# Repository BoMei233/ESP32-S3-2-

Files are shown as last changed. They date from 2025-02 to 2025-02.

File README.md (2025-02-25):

# ESP32-S3 欧卡2组合开关
使用PlatformIO，包含了源代码和模型文件，可以自己DIY组合开关

## 1. 购买清单
**后面我会给出我的购买截图，请注意型号**
| 名称 | 数量  |
| :---: | :---: |
| ESP32-S3开发板 | 1 |
| 104电容 |  16 |
| 加厚角码直角60x120x40 | 2 |
| 五菱荣光雨刷拨杆 A款 | 1 |
| 五菱荣光灯光拨杆 A款 | 1 |
| 4.8插簧线/条 |  13 |
| M3*5杯头螺丝 | 8 |
| M3x4x4.2热熔螺母 | 8 |
| M5法兰螺母 | 4 |
| M5*16杯头螺丝 | 4 |
| M5*12*1平垫圈 | 4 |
| 10P航插(插头+插座一套) | 1 |
| 8P航插(插头+插座一套) | 1 |
| 5x0.15平方硅胶线 | 1 |
| 8x0.15平方硅胶线 | 1 |
| 醋酸胶布(非必须，用于固定线束) | 1 |

### 注意事项：
1.角码需要在远端打个5mm的孔以适配V99基座，千万不要买大一号的\
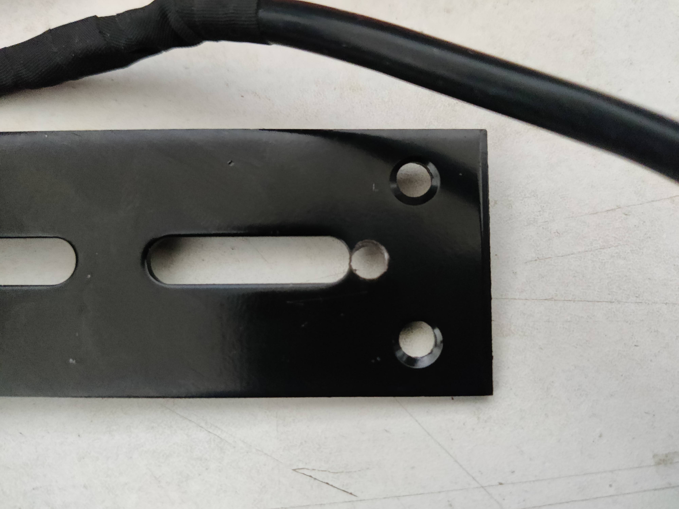
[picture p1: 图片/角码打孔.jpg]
角码打孔孔位


## 2. 组装步骤

### 2.1 转向灯开关
#### 2.1.1 转向灯开关插簧连接
    按照下图所示，将插簧线插入转向灯开关，插簧插入方向任意
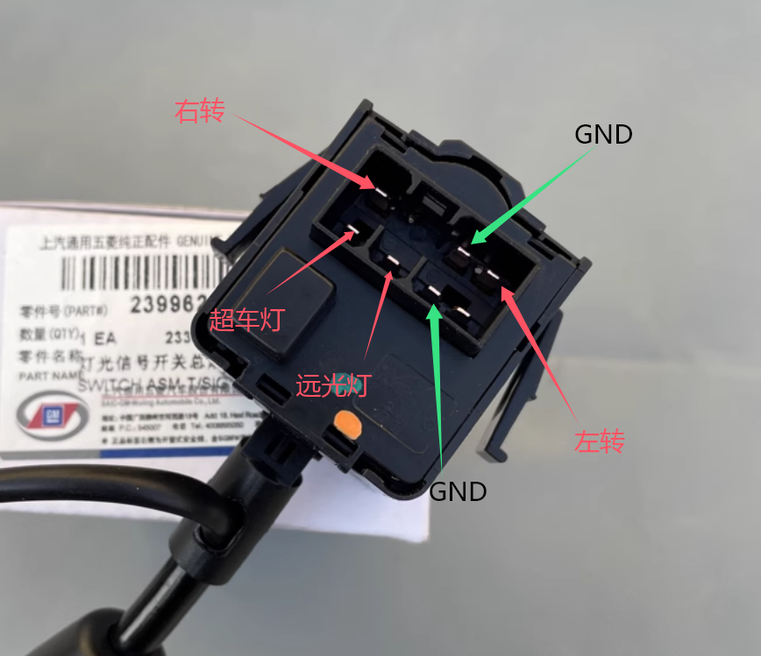
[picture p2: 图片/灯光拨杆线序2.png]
灯光拨杆线序2

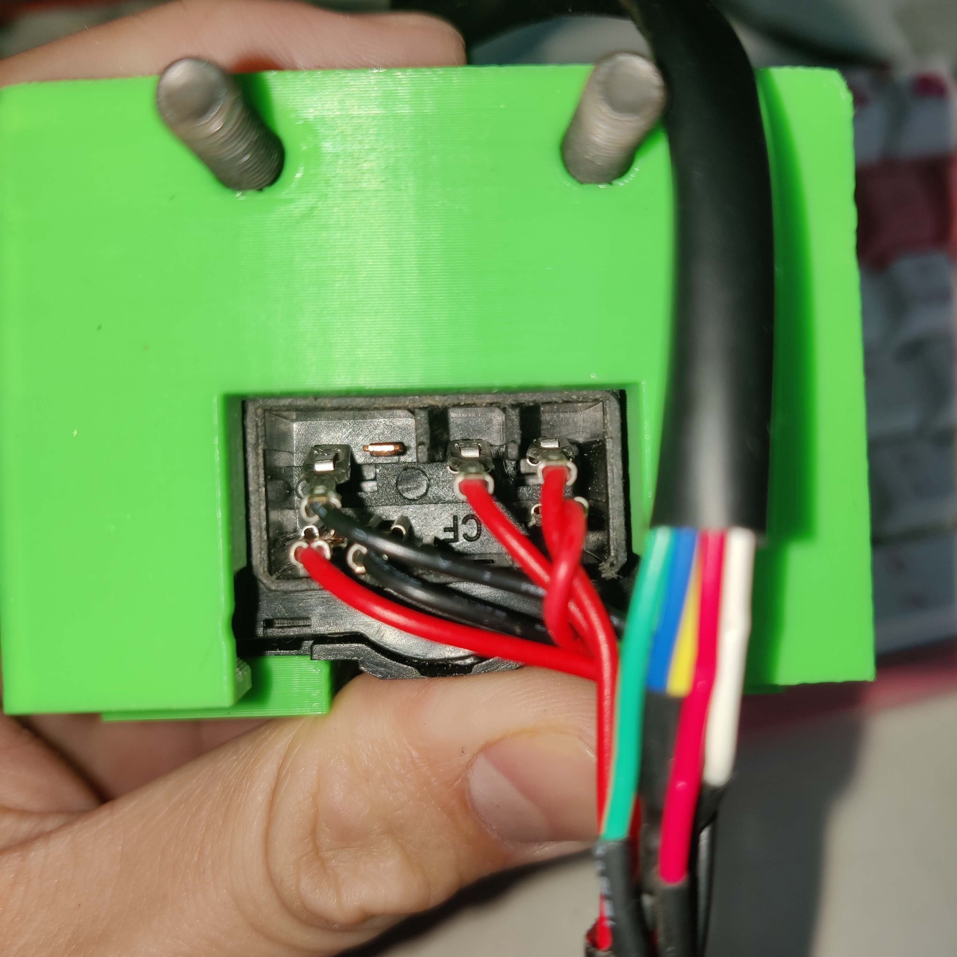
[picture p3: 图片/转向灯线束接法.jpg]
转向灯线束接法


#### 2.1.2 转向灯开关手柄线束连接
    下图给出了手柄五根线具体的作用，将两根GND与插簧线的GND并联在一起：
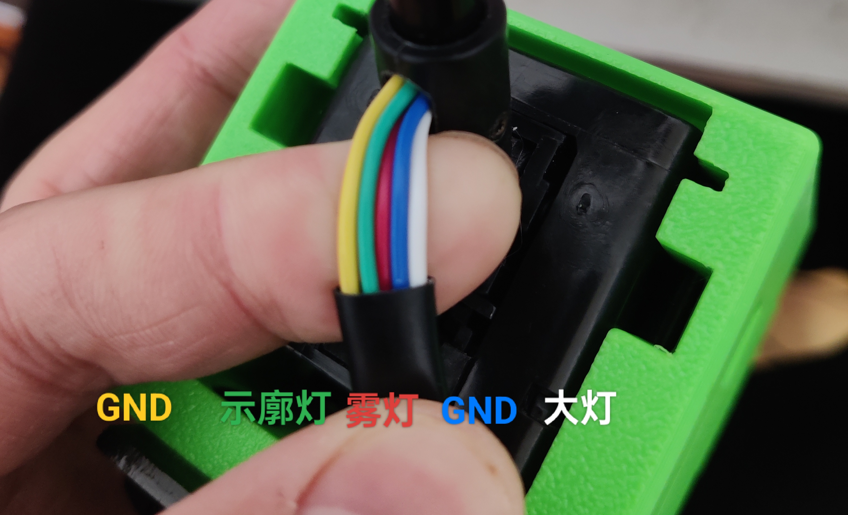
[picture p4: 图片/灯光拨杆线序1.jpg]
灯光拨杆线序1
\

至此，转向灯组合开关已经引出了8根线，将这8根线用“8x0.15平方硅胶线”延长，最后接到航空插头上。(请记住线序，航插上面会印有数字编号，这里买10P的用处是方便焊接，因为中间两根插针非常难焊接，因此使用四周的8根)

### 2.2 雨刮器开关
雨刮器相对简单，因为手柄没有线束，只需要插簧线。\
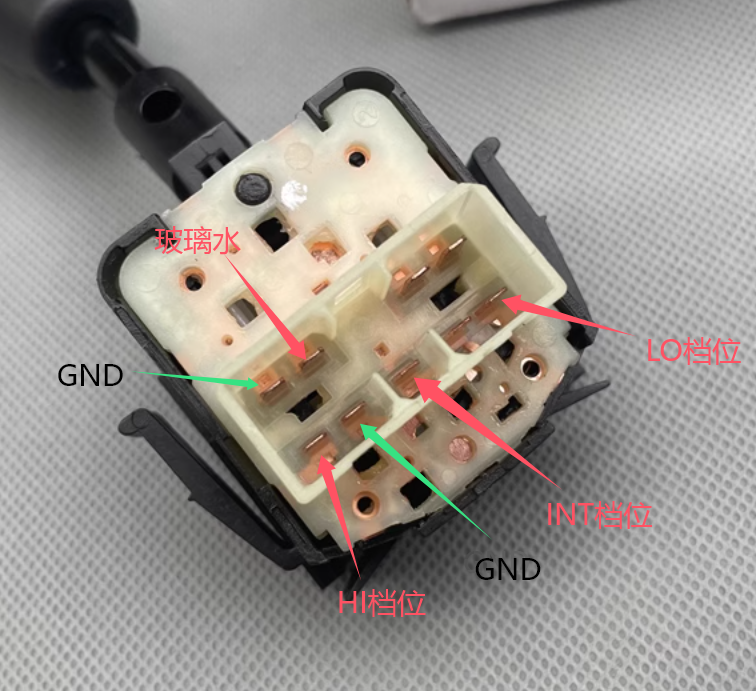
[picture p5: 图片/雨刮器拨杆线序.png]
雨刮器拨杆线序
\
现在将引出的5根线用“5x0.15平方硅胶线”延长，最后接到航空插头上。(请记住线序，航插上面会印有数字编号)

### 2.3 控制板组装
#### 2.3.1 控制板与洞洞板连接
这一步相对简单，只需要将航空插座上的引脚与开发板上的引脚对应连接起来就好，<span style="color: red;">记得在每个引脚与地之间并联一个104电容，这步非常重要！！！</span>如下图所示：
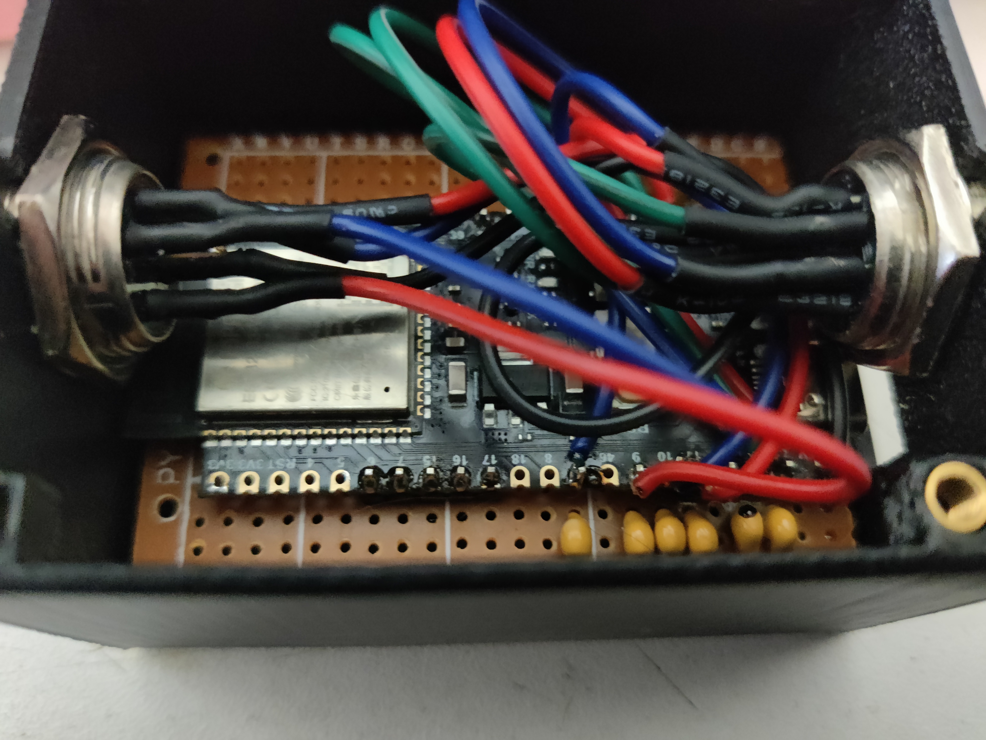
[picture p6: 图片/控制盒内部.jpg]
控制盒内部
\
使用洞洞板固定，将开发板焊接至洞洞板上即可，注意，需要将洞洞板短边剪去一排孔位，将USB接口与洞洞板边缘对齐，否则在装壳后USB线将无法插入。\
洞洞板尺寸为50x65mm，不一致的可以使用剪刀和砂纸进行修正。\
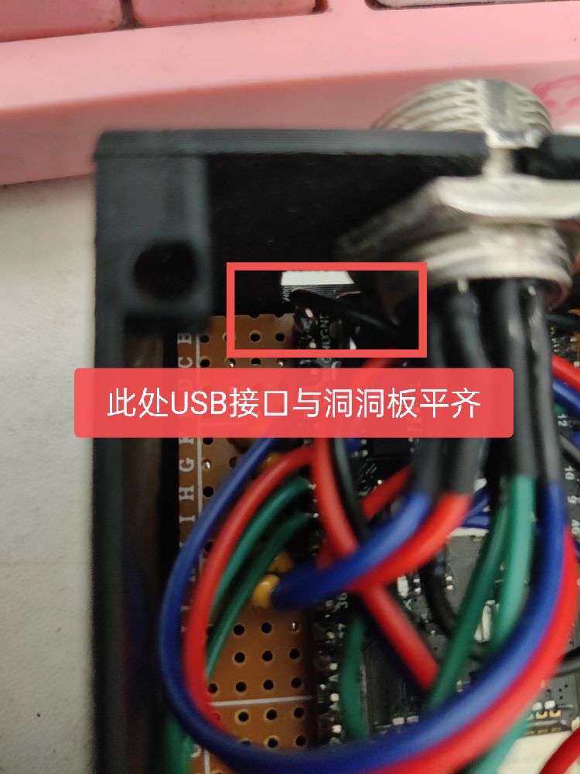
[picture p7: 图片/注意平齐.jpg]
注意平齐
\

#### 2.3.2 控制板与航空插座连接
这步就是单纯连线，没什么特别要注意的，按照下面的表格进行连接，线序我想你应该在焊接插头的时候记住了，没记住的拿万用表量一下。

| 开发板引脚 | 开关功能  |
| :---: | :---: |
| 21 | 左转 |
| 47 | 右转 |
| 48 | 雾灯 |
| 45 |  玻璃水 |
| 35 |  远光灯 |
| 14 |  示廓灯 |
| 13 | 大灯 |
| 11 | 雨刮器HI  |
| 10 | 雨刮器LO  |
| 9 | 雨刮器INT |
| 3 |  超车灯 |

OK，直到现在，就差外壳没安装了，现在可以将程序烧写进开发板，然后进游戏里测试一下。

### 2.4 外壳安装
我将我的模型上传到项目里了，格式是STP，可以下载来直接打印，也能方便修改，模型内部有个箭头，表示了组合开关的安装方向，模型与角码使用两个M5螺丝与螺母进行连接，安装好后效果如图所示：\
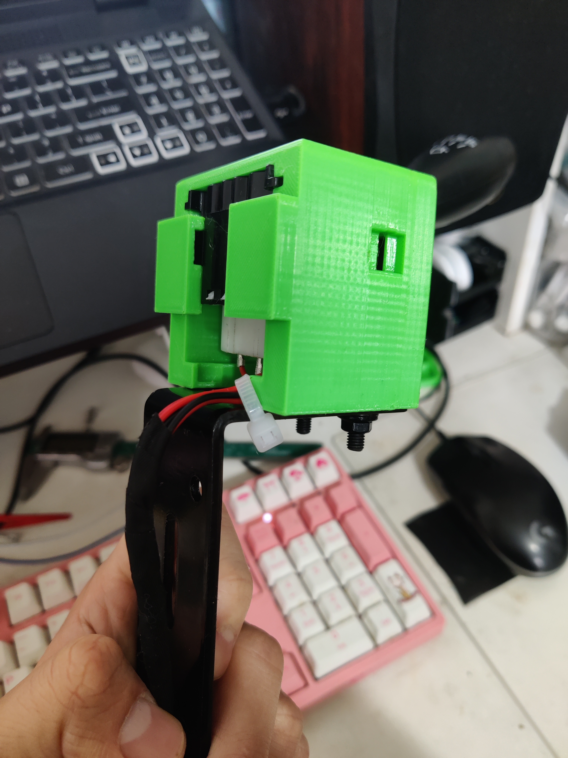
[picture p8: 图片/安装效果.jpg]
安装效果
\

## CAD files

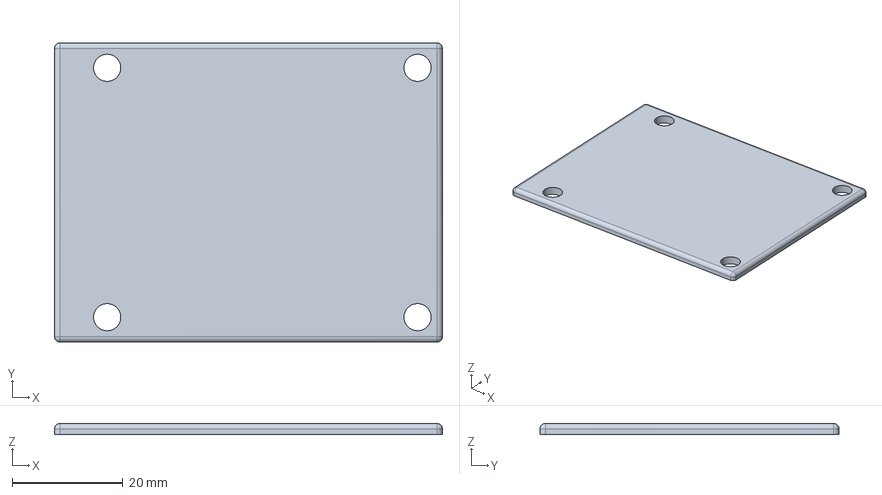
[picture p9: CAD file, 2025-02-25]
模型/控制器上盖.stp
70.0 x 54.0 x 2.00 mm

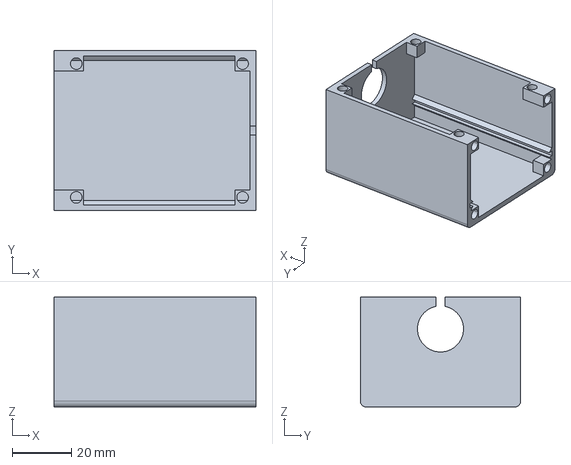
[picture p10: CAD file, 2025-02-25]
模型/控制盒V2.stp
68.0 x 54.0 x 37.0 mm

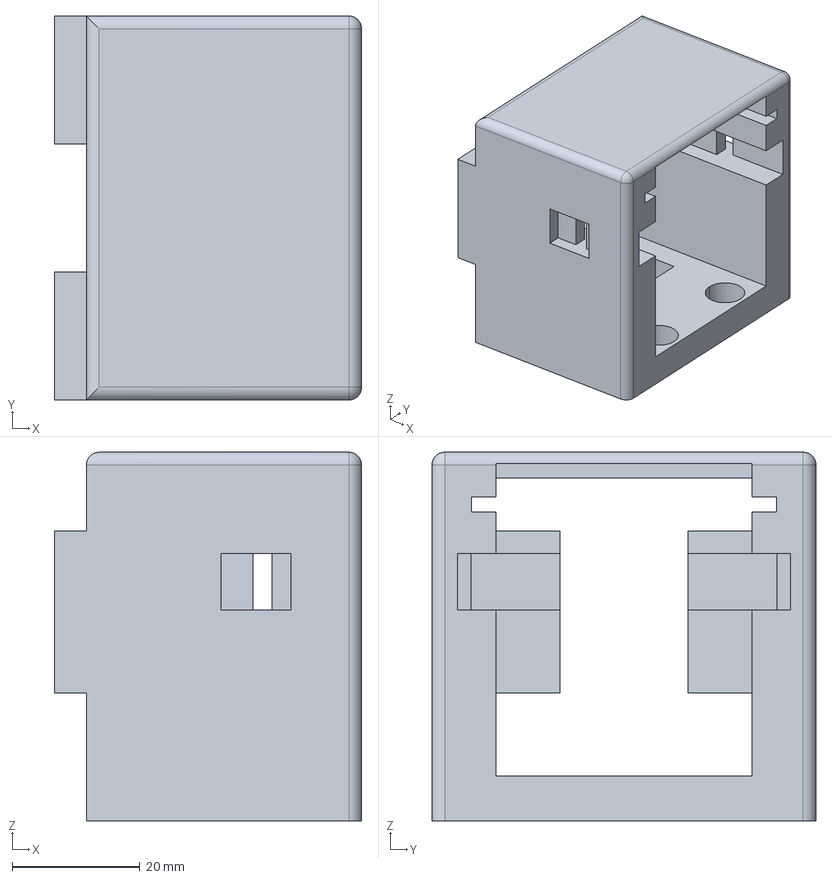
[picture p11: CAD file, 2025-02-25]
模型/开关支座_左右通用.stp
48.0 x 60.0 x 57.6 mm

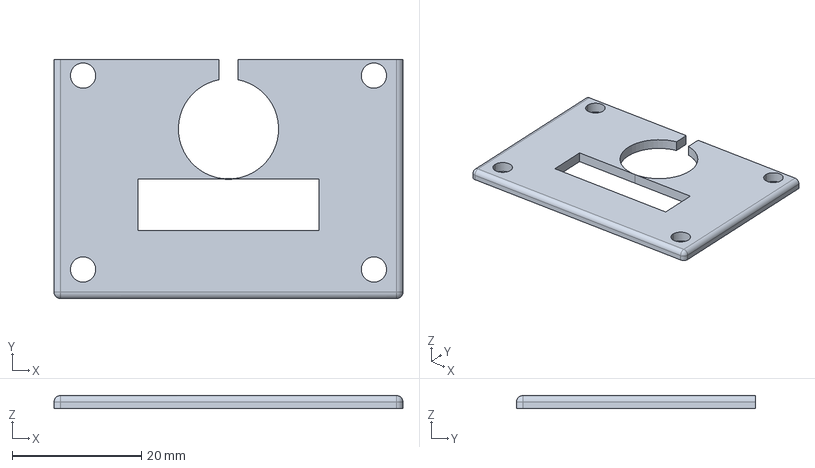
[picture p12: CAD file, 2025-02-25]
模型/控制器侧盖.stp
54.0 x 37.0 x 2.00 mm
